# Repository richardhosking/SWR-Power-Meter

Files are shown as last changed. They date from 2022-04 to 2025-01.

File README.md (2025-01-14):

# SWR-Power-Meter
High Performance HF Power meter using Arduino and a Directional Coupler
This device can measure power over a wide dynamic range from 10uW to 1 KW and will derive SWR for a 50 Ohm load 
The front end uses broadband Ferrite transformers in a Directional Coupler configuration 
AD8307 Logarithmic amplifiers derive power in a forward and reverse direction 
These drive an ADS1115 ADC for better resolution than the Arduino ADC can provide 
An Arduino Adafruit Trinket Pro 3V board performs calculations and drives a display
The display is an OLED - widely available but I2C is poorly docmented - see seprate README for details 
The KICAD PCB files are at https://github.com/richardhosking/PowerMeterKICAD

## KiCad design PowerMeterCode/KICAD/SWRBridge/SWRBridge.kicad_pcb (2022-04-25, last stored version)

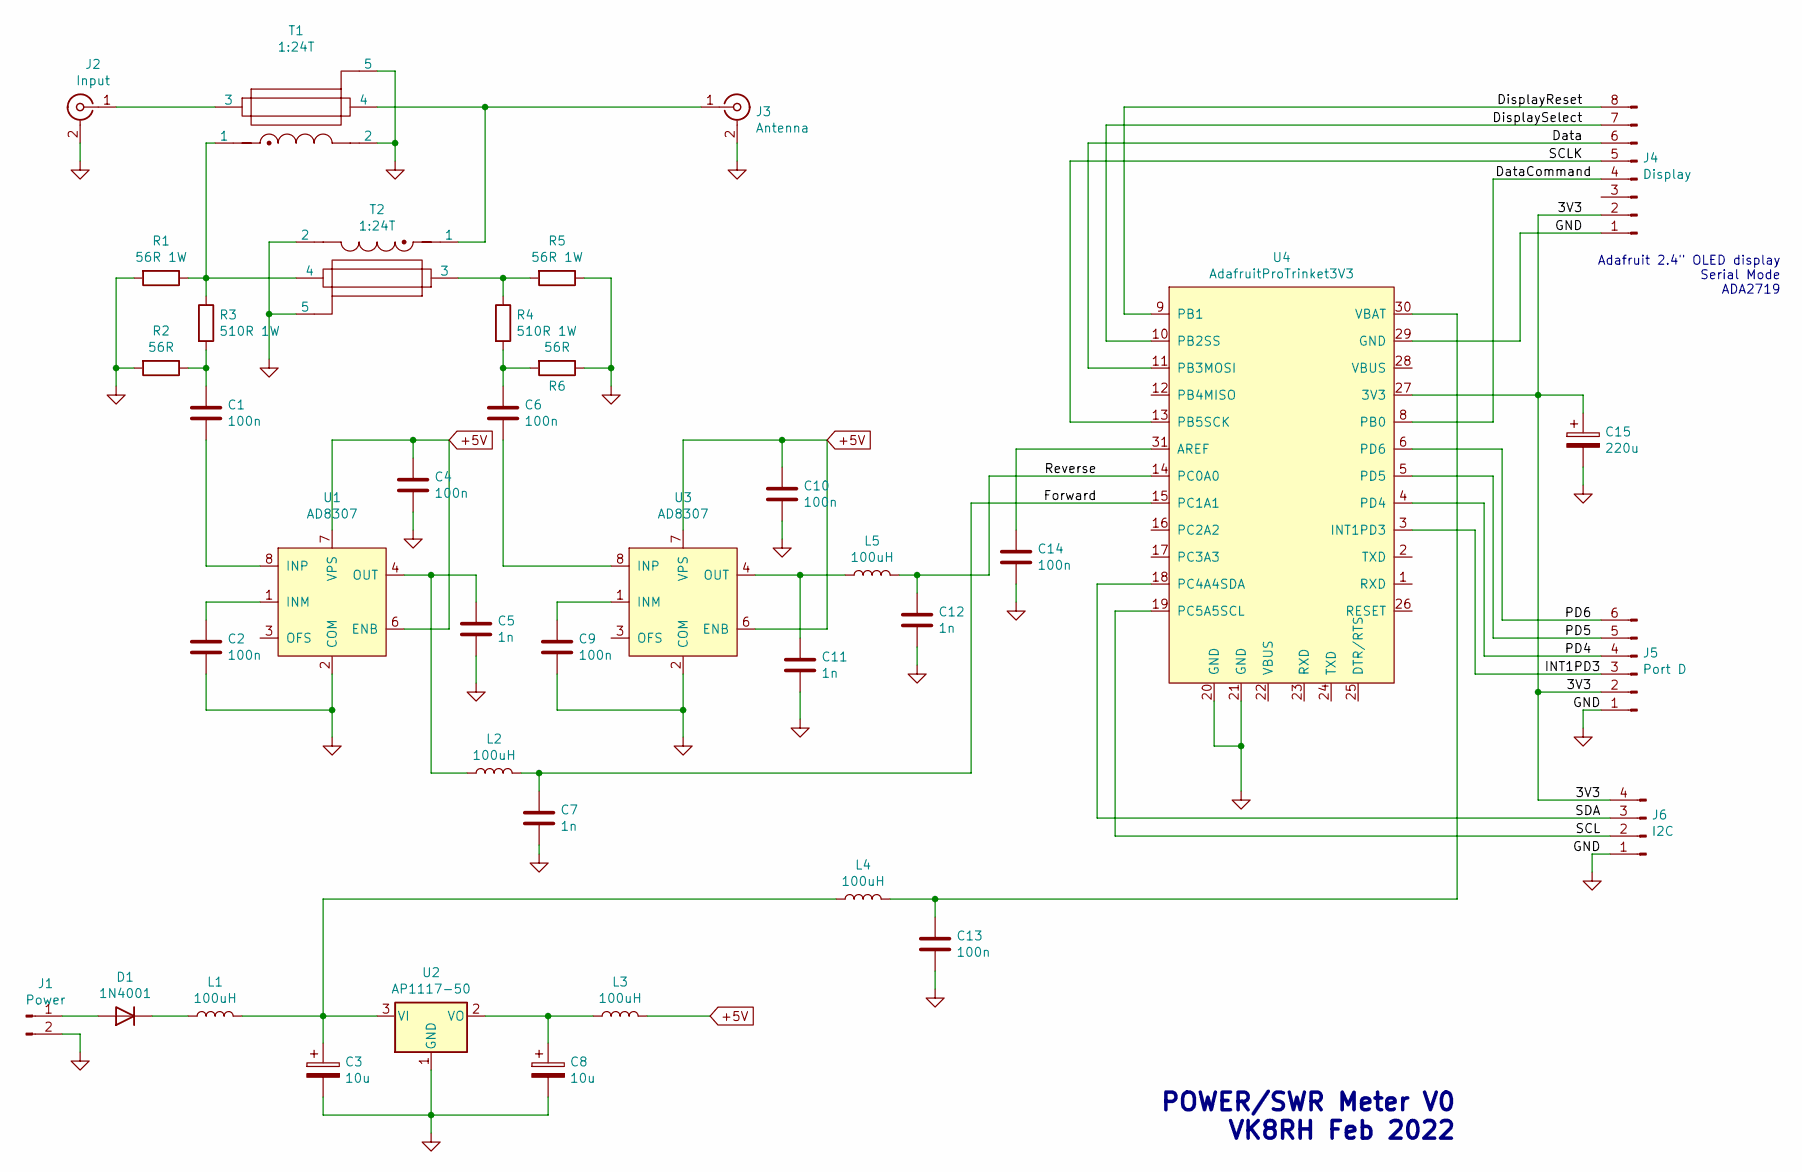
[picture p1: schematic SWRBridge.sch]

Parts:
C1, C2, C4, C6, C9, C10, C13, C14: 100n; C_1206_3216Metric_Pad1.33x1.80mm_HandSolder
C3, C8: 10u; CP_Elec_4x5.4
C5, C7, C11, C12: 1n; C_1206_3216Metric_Pad1.33x1.80mm_HandSolder
C15: 220u; CP_Elec_10x10
D1: 1N4001; D_1206_3216Metric_Pad1.42x1.75mm_HandSolder
J1: Power; PinHeader_1x02_P2.54mm_Vertical
J2: Input; Pad
J3: Antenna; Pad
J4: Display; PinHeader_1x08_P2.54mm_Vertical
J5: Port D; PinHeader_1x06_P2.54mm_Vertical
J6: I2C; PinHeader_1x04_P2.54mm_Vertical
L1, L2, L3, L4, L5: 100uH; L_1206_3216Metric_Pad1.42x1.75mm_HandSolder
R1, R5: 56R 1W; R_2512_6332Metric_Pad1.40x3.35mm_HandSolder
R2, R6: 56R; R_1206_3216Metric_Pad1.30x1.75mm_HandSolder
R3, R4: 510R 1W; R_2512_6332Metric_Pad1.40x3.35mm_HandSolder
T1, T2: 1:24T; SWRVoltageTransformer
U1, U3: AD8307; SO-8_3.9x4.9mm_P1.27mm
U2: AP1117-50; SOT-223-3_TabPin2
U4: AdafruitProTrinket3V3; AdafruitTrinketPro3V3

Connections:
+5V: C4.1, C10.1, L3.2, U1.6 (ENB), U1.7 (VPS), U3.6 (ENB), U3.7 (VPS)
/3V3: C15.1, J4.2, J5.2, J6.4, U4.27 (3V3)
/Data: J4.6, U4.11 (PB3MOSI)
/DataCommand: J4.4, U4.8 (PB0)
/DisplayReset: J4.8, U4.9 (PB1)
/DisplaySelect: J4.7, U4.10 (PB2SS)
/Forward: C7.1, L2.2, U4.15 (PC1A1)
/INT1PD3: J5.3, U4.3 (INT1PD3)
/PD4: J5.4, U4.4 (PD4)
/PD5: J5.5, U4.5 (PD5)
/PD6: J5.6, U4.6 (PD6)
/Reverse: C12.1, L5.2, U4.14 (PC0A0)
/SCL: J6.2, U4.19 (PC5A5SCL)
/SCLK: J4.5, U4.13 (PB5SCK)
/SDA: J6.3, U4.18 (PC4A4SDA)
GND: C2.2, C3.2, C4.2, C5.2, C7.2, C8.2, C9.2, C10.2, C11.2, C12.2, C13.2, C14.2, C15.2, J1.2, J2.2 (Ext), J3.2 (Ext), J4.1, J5.1, J6.1, R1.2, R2.2, R5.1, R6.1, T1.2, T1.5, T2.2, T2.5, U1.2 (COM), U2.1 (GND), U3.2 (COM), U4.20 (GND), U4.21 (GND), U4.29 (GND)
unnamed: C1.1, R2.1, R3.2
unnamed: C1.2, U1.8 (INP)
unnamed: C2.1, U1.1 (INM)
unnamed: C3.1, L1.2, L4.1, U2.3 (VI)
unnamed: C5.1, L2.1, U1.4 (OUT)
unnamed: C6.1, R4.2, R6.2
unnamed: C6.2, U3.8 (INP)
unnamed: C8.1, L3.1, U2.2 (VO)
unnamed: C9.1, U3.1 (INM)
unnamed: C11.1, L5.1, U3.4 (OUT)
unnamed: C13.1, L4.2, U4.30 (VBAT)
unnamed: C14.1, U4.31 (AREF)
unnamed: D1.1 (K), L1.1
unnamed: D1.2 (A), J1.1
unnamed: J2.1 (In), T1.3
unnamed: J3.1 (In), T1.4, T2.1
unnamed: R1.1, R3.1, T1.1, T2.4
unnamed: R4.1, R5.2, T2.3

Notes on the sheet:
Adafruit 2.4" OLED display Serial Mode ADA2719
POWER/SWR Meter V0 VK8RH Feb 2022

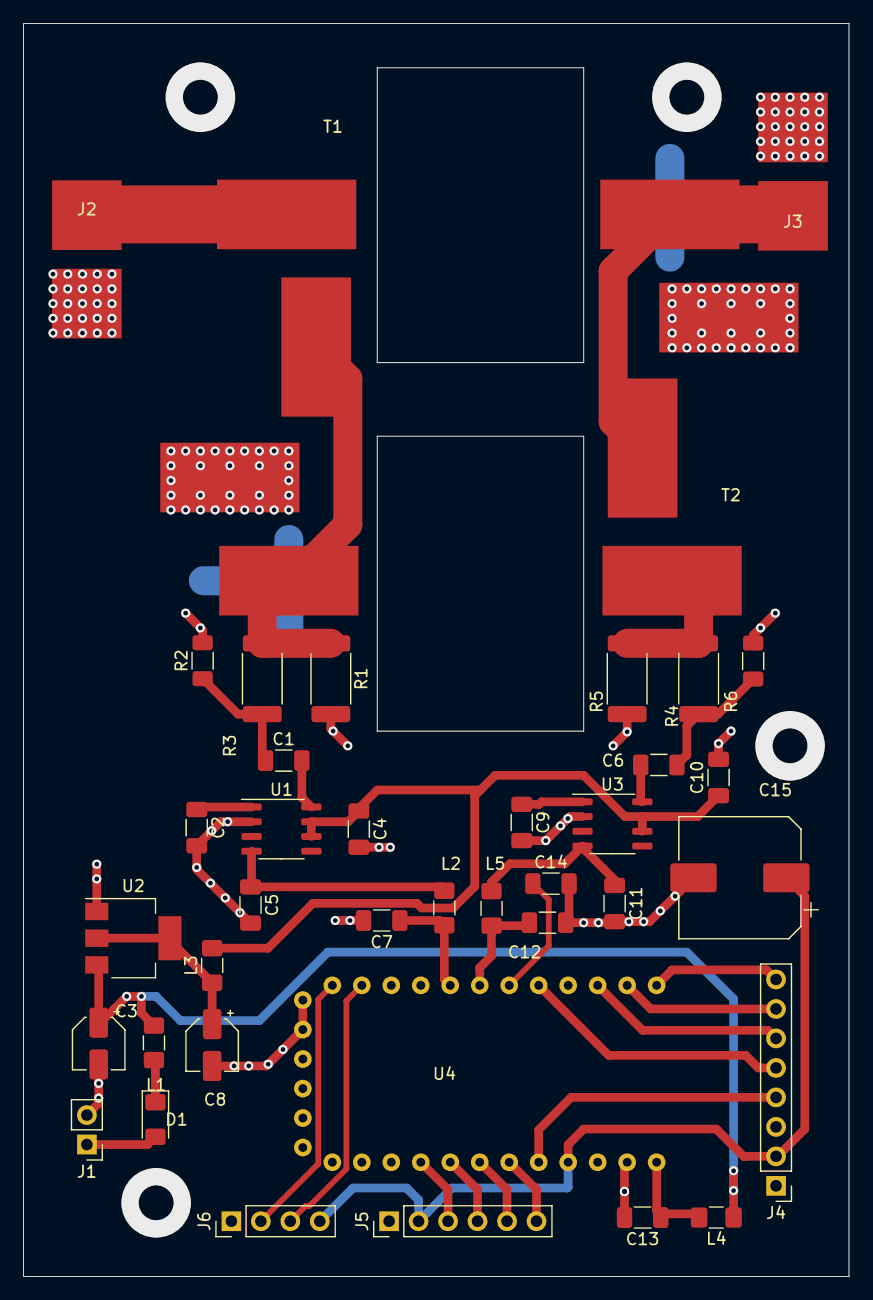
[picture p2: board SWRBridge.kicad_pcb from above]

Board: 2 copper layers, 71.1 x 108.0 mm, 39 parts (0 on the bottom side), 34 nets.

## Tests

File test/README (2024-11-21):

Driving the MCOB128064JX OLED Display
There is a datasheet at  https://midasdisplays.com/wp-content/uploads/2023/08/MCOB128064JX-YM.pdf

However it gives limited data as to drive the display in various interface formats 
For I2C 

(1) Set jumpers JB1 High
                JB2 Low 
(2) Pin 1 VCC 
    Pin 2 GND 
    Pin 4 SCL 
    Pin 5 SDA 
    Pin 12 Chip Select (Low)
    Pin 14 Reset (Low)
    Pin 16 High - read data from Display, Low - Command to display
    Pin 6-11 parallel data - grounded

(3) Set I2C address (J1C ? Open)
    0x3C // 011110+SA0+RW - 0x3C or 0x3D     

Library has constructors for I2C, Software SPI , Hardware SPI 
Using I2C in this case

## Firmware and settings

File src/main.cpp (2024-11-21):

/**************************************************
 * Power Meter Code Oct 2024
 * Richard Hosking VK8RH Nov 2022
 * 
 * Using Adafruit Pro Trinket 3.3V 
 * 
 * Custom Directional coupler/Log amplifier/SWR detector board
 *   
 * OLED Display MCOB128064JX-YM 
 * This uses an SSD1309 driver
 * but appears to work with the SSD1305 Adafruit Library
 *   
 *************************************************/

#include <Wire.h>
#include <SPI.h>

// Display 
#include "display.h"

// Custom Library to drive Diectional Coupler Board
#include "powerMeter.h"

// Custom Library to drive ADS1015 ADC
//#include "ADS1X15.h"

// And setup display
#define SCREEN_WIDTH 128 // OLED display width, in pixels
#define SCREEN_HEIGHT 64 // OLED display height, in pixels
#define OLED_RESET     9 // Reset pin # (or -1 if sharing Arduino reset pin)
#define DISPLAY_ADDRESS 0x3C // Set by grounding Pin 16 on display SA0 LOW
#define SPEED_BEFORE     100000 // I2C setup speed 100KHz is a safe option
#define SPEED_AFTER      100000 // I2C data speed - safe option 
// Display object
Display display(SCREEN_WIDTH, SCREEN_HEIGHT, &Wire, OLED_RESET, SPEED_BEFORE, SPEED_AFTER);

// Declare power meter object
PowerSWRMeter meter;

void setup() {
  
  // If we can get the display to work can use it for debugging
  // (No FTDI/serial to USB interface on Pro Trinket)
  // Clear the buffer
  display.begin(DISPLAY_ADDRESS, true);
  display.clearDisplay();
  display.display();
  
// Set up display  
  display.setTextSize(1);
  display.setTextColor(WHITE);
  display.setCursor(0,0);
  display.println("Power Meter VK3BFX");
  display.display();
  delay(1000);
  if(!meter.adc.begin()) {
    display.println(F("adc setup failed - check connections"));
    for(;;); // Don't proceed, loop forever
  }     
  delay(1000);
}

void loop() {
  display.clearDisplay();
  display.setTextSize(1);

  display.setCursor(0,10);
  display.print("Power: ");
  display.print(meter.calculatePower());
  // display Power unit
  if (meter.point==0){
    display.println(" uW ");
    }
  else if(meter.point==1){
    display.println(" mW ");
    }
  else{
    display.println(" W ");
    }
  // dBm
  display.print("       ");
  display.print(meter.getForward());
  display.println(" dBm");
  display.println("  ");

  // and SWR
  display.setTextSize(2);
  display.print("SWR: ");
  display.println(meter.calculateSWR());
  display.display();
  // Repeat every half second or so 
  delay(500);  
}

// End of code
                        

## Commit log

2024-07-09 Delete PowerMeterCode/KICAD/SWRBridge directory
    Move KICAD to separate Repo
    [SWRBridge.kicad_pcb, SWRBridge.sch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]
2024-11-21 Update README.md
    Details of ADC and OLED
2024-11-21 Update README.md
    Address for KICAD files
